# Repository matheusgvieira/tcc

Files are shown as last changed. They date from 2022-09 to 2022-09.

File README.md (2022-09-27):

# Desenvolvimento de protótipo funcional de hardware e firmware para monitoramento de instalações CC de sistemas fotovoltaicos

Este trabalho tem por objetivo o desenvolvimento de um hadware e firmware para o monitoramento, em tempo real, de caixas de junção de sistemas fotovoltaicos, viabilizando o acompanhamento de variáveis elétricas e estado de operação dos equipamentos.

### Estrututra

- Hardware: contém todos esquemáticos e layout de placa de circuito impressos, desenvolvidos no Altium.
- Firmware: contém o código fonte da placa de coleta de dados e da placa de comunicação, no CubeIde e ESP-IDF, respectivamente.
- Software: containers para criação do broker MQTT e o Dashboard no Node-red

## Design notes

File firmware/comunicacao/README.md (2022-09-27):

# Comunication Modulo

> The firmware from Tcc Project can perform the below features:
> Controller and send of data to MQTT Broker.

* Send data sensors to MQTT Broker

## Actuators

* Led

## Protocols

* UART
* MQTT

## Comandos ESP-IDF

1. Set enviroments of espressif idf
```sh
cd $HOME
. $HOME/esp/esp-idf/export.sh
```

3. Set develop board and settings configurations
```sh
idf.py set-target esp32
idf.py menuconfig
```

4. Build of project
```sh
idf.py build
```

5. Upload project in develop board
```sh
idf.py -p PORT [-b BAUD] flash
idf.py -p PORT flash monitor
```

6. See screen monitor
```sh
screen /dev/ttyUSB0 115200
```

## Dashboard
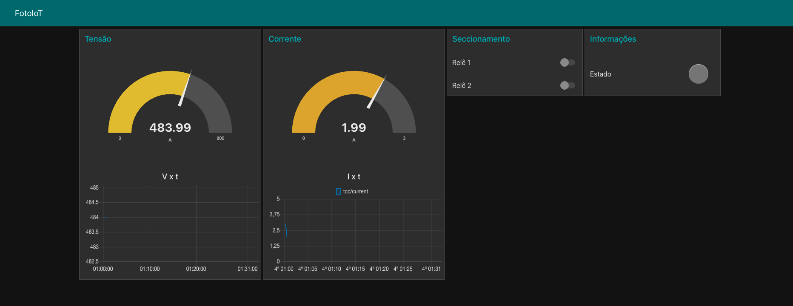
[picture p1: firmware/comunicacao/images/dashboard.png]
Dashboard


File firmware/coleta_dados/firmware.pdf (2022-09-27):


01/11/2021

## firmware Project Configuration Report

# 1. Description

## 1.1. Project

Project Name | firmware
Board Name | NUCLEO-G474RE
Generated with: | STM32CubeMX 6.3.0
Date | 11/01/2021

## 1.2. MCU

MCU Series | STM32G4
MCU Line | STM32G4x4
MCU name | STM32G474RETx
MCU Package | LQFP64
MCU Pin number | 64

## 1.3. Core(s) information

Core(s) | ARM Cortex-M4

# 2. Pinout Configuration

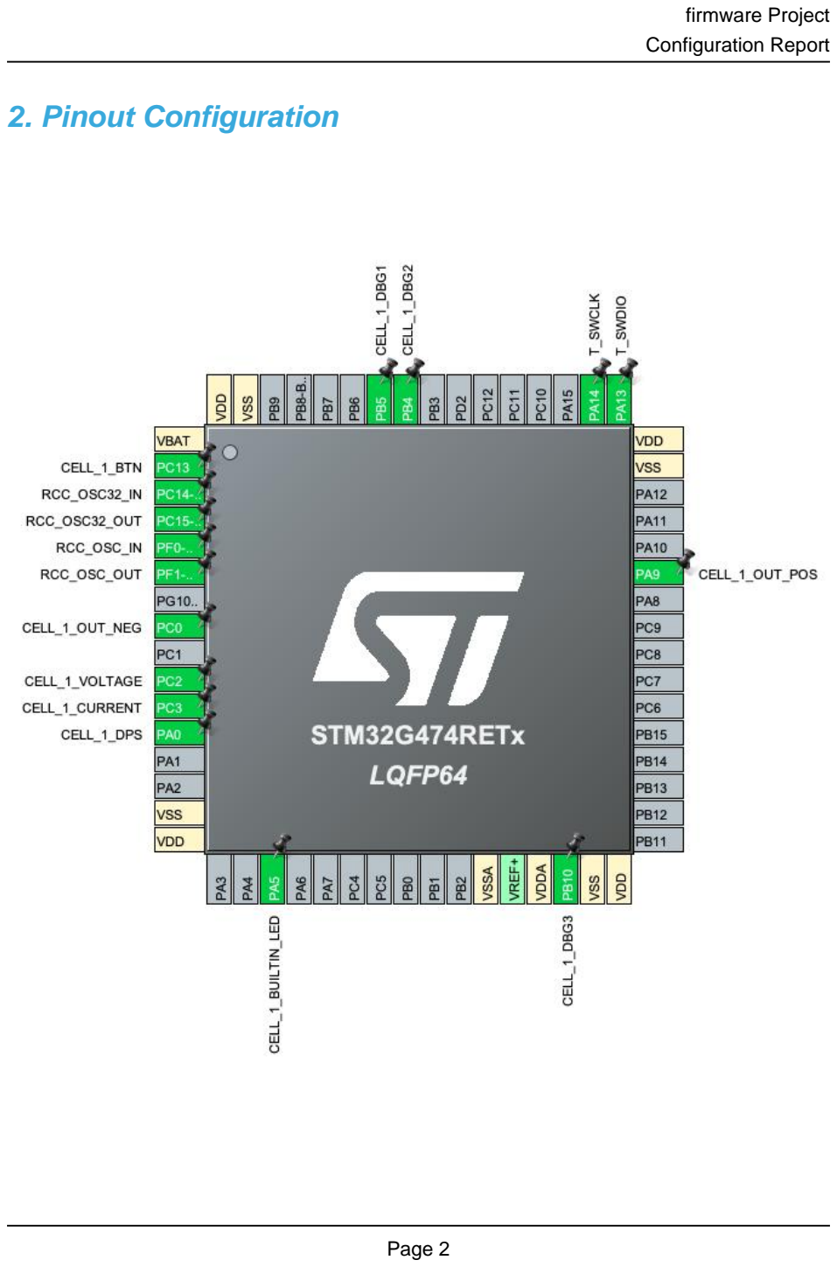
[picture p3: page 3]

# 3. Pins Configuration

Pin Number LQFP64 | Pin Name (function after reset) | Pin Type | Alternate Function(s) | Label
1 | VBAT | Power
2 | PC13 | I/O | GPIO_EXTI13 | CELL_1_BTN
3 | PC14-OSC32_IN | I/O | RCC_OSC32_IN
4 | PC15-OSC32_OUT | I/O | RCC_OSC32_OUT
5 | PF0-OSC_IN | I/O | RCC_OSC_IN
6 | PF1-OSC_OUT | I/O | RCC_OSC_OUT
8 | PC0 * | I/O | GPIO_Output | CELL_1_OUT_NEG
10 | PC2 | I/O | ADC1_IN8 | CELL_1_VOLTAGE
11 | PC3 | I/O | ADC2_IN9 | CELL_1_CURRENT
12 | PA0 | I/O | GPIO_EXTI0 | CELL_1_DPS
15 | VSS | Power
16 | VDD | Power
19 | PA5 * | I/O | GPIO_Output | CELL_1_BUILTIN_LED
27 | VSSA | Power
29 | VDDA | Power
30 | PB10 * | I/O | GPIO_Output | CELL_1_DBG3
31 | VSS | Power
32 | VDD | Power
43 | PA9 * | I/O | GPIO_Output | CELL_1_OUT_POS
47 | VSS | Power
48 | VDD | Power
49 | PA13 | I/O | SYS_JTMS-SWDIO | T_SWDIO
50 | PA14 | I/O | SYS_JTCK-SWCLK | T_SWCLK
57 | PB4 * | I/O | GPIO_Output | CELL_1_DBG2
58 | PB5 * | I/O | GPIO_Output | CELL_1_DBG1
63 | VSS | Power
64 | VDD | Power

## * The pin is affected with an I/O function

# 4. Clock Tree Configuration

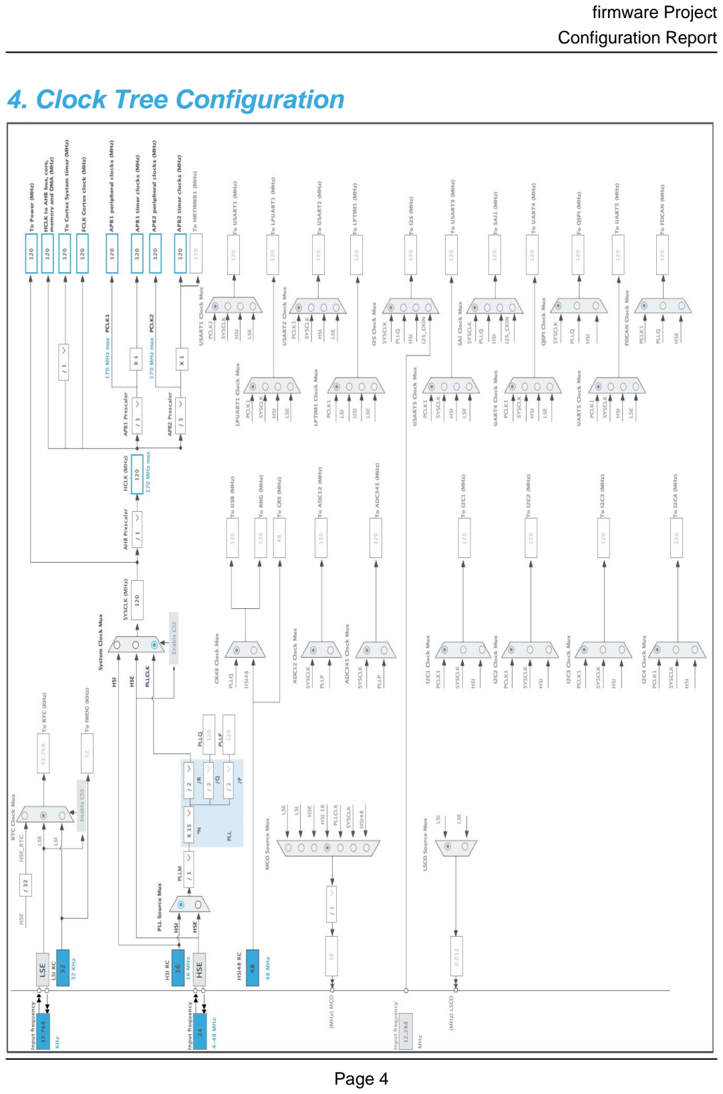
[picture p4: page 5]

# 5. Software Project

## 5.1. Project Settings

Name | Value
Project Name | firmware
Project Folder | /Users/rfeijoo/Documents/OneDrive/CubeMX/firmware
Toolchain / IDE | STM32CubeIDE
Firmware Package Name and Version | STM32Cube FW_G4 V1.4.0
Application Structure | Advanced
Generate Under Root | Yes
Do not generate the main() | No
Minimum Heap Size | 0x200
Minimum Stack Size | 0x400

## 5.2. Code Generation Settings

Name | Value
STM32Cube MCU packages and embedded software | Copy only the necessary library files
Generate peripheral initialization as a pair of '.c/.h' files | Yes
Backup previously generated files when re-generating | No
Keep User Code when re-generating | Yes
Delete previously generated files when not re-generated | Yes
Set all free pins as analog (to optimize the power consumption) | No
Enable Full Assert | No

## 5.3. Advanced Settings - Generated Function Calls

Rank | Function Name | Peripheral Instance Name
1 | MX_GPIO_Init | GPIO
2 | SystemClock_Config | RCC
3 | MX_TIM1_Init | TIM1
4 | MX_ADC1_Init | ADC1
5 | MX_ADC2_Init | ADC2
6 | MX_ADC5_Init | ADC5
7 | MX_TIM2_Init | TIM2

# 6. Power Consumption Calculator report

## 6.1. Microcontroller Selection

Series | STM32G4
Line | STM32G4x4
MCU | STM32G474RETx
Datasheet | DS12288_Rev0

## 6.2. Parameter Selection

Temperature | 25
Vdd | 3.0

## 6.3. Battery Selection

Battery | Li-SOCL2(A3400)
Capacity | 3400.0 mAh
Self Discharge | 0.08 %/month
Nominal Voltage | 3.6 V
Max Cont Current | 100.0 mA
Max Pulse Current | 200.0 mA
Cells in series | 1
Cells in parallel | 1

## 6.4. Sequence

Step | Step1 | Step2
Mode | RUN | STOP1
Vdd | 3.0 | 3.0
Voltage Source | Battery | Battery
Range | Range1-Boost | NoRange
Fetch Type | FLASH/DualBank/ART | NA
CPU Frequency | 170 MHz | 0 Hz
Clock Configuration | HSE BYP PLL | ALL CLOCKS OFF
Clock Source Frequency | 4 MHz | 0 Hz

### Peripherals

Additional Cons. | 0 mA | 0 mA
Average Current | 29.5 mA | 80.5 µA
Duration | 0.1 ms | 0.9 ms
DMIPS | 213.0 | 0.0
Ta Max | 124.25 | 129.98
Category | In DS Table | In DS Table

## 6.5. Results

Sequence Time | 1 ms | Average Current | 3.02 mA
Battery Life | 1 month, 16 days, 9 hours | Average DMIPS | 212.5 DMIPS

## 6.6. Chart

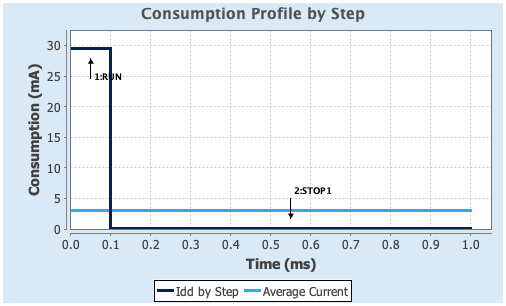
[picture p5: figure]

# 7. Peripherals and Middlewares Configuration

## 7.1. ADC1 IN8: IN8 Single-ended

## 7.1.1. Parameter Settings:

### ADCs_Common_Settings:

Mode | Dual regular simultaneous mode only *
DMA Access Mode | DMA access mode disabled
Delay between 2 sampling phases | 1 Cycle

### ADC_Settings:

Clock Prescaler | Synchronous clock mode divided by 2
Resolution | ADC 12-bit resolution
Data Alignment | Right alignment
Gain Compensation | 0
Scan Conversion Mode | Disabled
End Of Conversion Selection | End of sequence of conversion *
Low Power Auto Wait | Disabled
Continuous Conversion Mode | Disabled
Discontinuous Conversion Mode | Disabled
DMA Continuous Requests | Disabled
Overrun behaviour | Overrun data preserved

### ADC_Regular_ConversionMode:

Enable Regular Conversions | Enable
Enable Regular Oversampling | Disable
Number Of Conversion | 1
External Trigger Conversion Source | Regular Conversion launched by software
External Trigger Conversion Edge | None
Rank | 1
Channel | Channel 8
Sampling Time | 2.5 Cycles
Offset Number | No offset

### ADC_Injected_ConversionMode:

Enable Injected Conversions | Disable

### Analog Watchdog 1:

Enable Analog WatchDog1 Mode | false

### Analog Watchdog 2:

Enable Analog WatchDog2 Mode | false

### Analog Watchdog 3:

Enable Analog WatchDog3 Mode | false

## 7.2. ADC2 IN9: IN9 Single-ended

## 7.2.1. Parameter Settings:

### ADCs_Common_Settings:

Mode | Dual regular simultaneous mode only *
DMA Access Mode | DMA access mode disabled
Delay between 2 sampling phases | 1 Cycle

### ADC_Settings:

Clock Prescaler | Synchronous clock mode divided by 2
Resolution | ADC 12-bit resolution
Data Alignment | Right alignment
Gain Compensation | 0
Scan Conversion Mode | Disabled
End Of Conversion Selection | End of sequence of conversion *
Low Power Auto Wait | Disabled
Continuous Conversion Mode | Disabled
Discontinuous Conversion Mode | Disabled
DMA Continuous Requests | Disabled
Overrun behaviour | Overrun data preserved

### ADC_Regular_ConversionMode:

Enable Regular Conversions | Enable
Enable Regular Oversampling | Disable
Number Of Conversion | 1
Rank | 1
Channel | Channel 9
Sampling Time | 2.5 Cycles
Offset Number | No offset

### ADC_Injected_ConversionMode:

Enable Injected Conversions | Disable

### Analog Watchdog 1:

Enable Analog WatchDog1 Mode | false

### Analog Watchdog 2:

Enable Analog WatchDog2 Mode | false

### Analog Watchdog 3:

Enable Analog WatchDog3 Mode | false

## 7.3. ADC5 mode: Temperature Sensor Channel mode: Vrefint Channel

## 7.3.1. Parameter Settings:

### ADC_Settings:

Clock Prescaler | Synchronous clock mode divided by 2
Resolution | ADC 12-bit resolution
Data Alignment | Right alignment
Gain Compensation | 0
Scan Conversion Mode | Disabled
End Of Conversion Selection | End of single conversion
Low Power Auto Wait | Disabled
Continuous Conversion Mode | Disabled
Discontinuous Conversion Mode | Disabled
DMA Continuous Requests | Disabled
Overrun behaviour | Overrun data preserved

### ADC_Regular_ConversionMode:

Enable Regular Conversions | Enable
Enable Regular Oversampling | Disable
Number Of Conversion | 1
External Trigger Conversion Source | Regular Conversion launched by software
External Trigger Conversion Edge | None
Rank | 1
Channel | Channel Temperature Sensor
Sampling Time | 640.5 Cycles *
Offset Number | No offset

### ADC_Injected_ConversionMode:

Enable Injected Conversions | Disable

### Analog Watchdog 1:

Enable Analog WatchDog1 Mode | false

### Analog Watchdog 2:

Enable Analog WatchDog2 Mode | false

### Analog Watchdog 3:

Enable Analog WatchDog3 Mode | false

## 7.4. RCC

## High Speed Clock (HSE): Crystal/Ceramic Resonator Low Speed Clock (LSE) : Crystal/Ceramic Resonator

## 7.4.1. Parameter Settings:

### System Parameters:

VDD voltage (V) | 3.3
Instruction Cache | Enabled
Prefetch Buffer | Disabled
Data Cache | Enabled
Flash Latency(WS) | 3 WS (4 CPU cycle)

### RCC Parameters:

HSI Calibration Value | 64
HSE Startup Timout Value (ms) | 100
LSE Startup Timout Value (ms) | 5000

### Power Parameters:

Power Regulator Voltage Scale | Power Regulator Voltage Scale 1

### Peripherals Clock Configuration:

Generate the peripherals clock configuration | TRUE

## 7.5. SYS Debug: Serial Wire Timebase Source: SysTick mode: save power of non-active UCPD - deactive Dead Battery pull-up

## 7.6. TIM1 Clock Source : Internal Clock

## 7.6.1. Parameter Settings:

### Counter Settings:

Prescaler (PSC - 16 bits value) | 119 *
Counter Mode | Up
Dithering | Disable
Counter Period (AutoReload Register - 16 bits value ) | 1041 *
Internal Clock Division (CKD) | No Division
Repetition Counter (RCR - 16 bits value) | 0
auto-reload preload | Enable *

### Trigger Output (TRGO) Parameters:

Master/Slave Mode (MSM bit) | Disable (Trigger input effect not delayed)
Trigger Event Selection TRGO | Reset (UG bit from TIMx_EGR)
Trigger Event Selection TRGO2 | Reset (UG bit from TIMx_EGR)

## 7.7. TIM2 Clock Source : Internal Clock

## 7.7.1. Parameter Settings:

### Counter Settings:

Prescaler (PSC - 16 bits value) | 11999 *
Counter Mode | Up
Dithering | Disable
Counter Period (AutoReload Register - 32 bits value ) | 10000 *
Internal Clock Division (CKD) | No Division
auto-reload preload | Enable *

### Trigger Output (TRGO) Parameters:

Master/Slave Mode (MSM bit) | Disable (Trigger input effect not delayed)
Trigger Event Selection TRGO | Reset (UG bit from TIMx_EGR)

### * User modified value

# 8. System Configuration

## 8.1. GPIO configuration

IP | Pin | Signal | GPIO mode | GPIO pull/up pull down | Max Speed | User Label
ADC1 | PC2 | ADC1_IN8 | Analog mode | No pull-up and no pull-down | n/a | CELL_1_VOLTAGE
ADC2 | PC3 | ADC2_IN9 | Analog mode | No pull-up and no pull-down | n/a | CELL_1_CURRENT
RCC | PC14-OSC32_IN | RCC_OSC32_IN | n/a | n/a | n/a
| PC15-OSC32_OU T | RCC_OSC32_O UT | n/a | n/a | n/a
| PF0-OSC_IN | RCC_OSC_IN | n/a | n/a | n/a
| PF1-OSC_OUT | RCC_OSC_OUT | n/a | n/a | n/a
SYS | PA13 | SYS_JTMS-SWDIO | n/a | n/a | n/a | T_SWDIO
| PA14 | SYS_JTCK-SWCLK | n/a | n/a | n/a | T_SWCLK
GPIO | PC13 | GPIO_EXTI13 | External Interrupt Mode with Rising edge trigger detection | No pull-up and no pull-down | n/a | CELL_1_BTN
| PC0 | GPIO_Output | Output Push Pull | No pull-up and no pull-down | Low | CELL_1_OUT_NEG
| PA0 | GPIO_EXTI0 | External Interrupt Mode with Rising/Falling edge | No pull-up and no pull-down | n/a | CELL_1_DPS
| PA5 | GPIO_Output | Output Push Pull | No pull-up and no pull-down | Low | CELL_1_BUILTIN_LED
| PB10 | GPIO_Output | Output Push Pull | No pull-up and no pull-down | Low | CELL_1_DBG3
| PA9 | GPIO_Output | Output Push Pull | No pull-up and no pull-down | Low | CELL_1_OUT_POS
| PB4 | GPIO_Output | Output Push Pull | No pull-up and no pull-down | Low | CELL_1_DBG2
| PB5 | GPIO_Output | Output Push Pull | No pull-up and no pull-down | Low | CELL_1_DBG1

## 8.2. DMA configuration

## nothing configured in DMA service

## 8.3. NVIC configuration

## 8.3.1. NVIC

Interrupt Table | Enable | Preenmption Priority | SubPriority
Non maskable interrupt | true | 0 | 0
Hard fault interrupt | true | 0 | 0
Memory management fault | true | 0 | 0
Prefetch fault, memory access fault | true | 0 | 0
Undefined instruction or illegal state | true | 0 | 0
System service call via SWI instruction | true | 0 | 0
Debug monitor | true | 0 | 0
Pendable request for system service | true | 0 | 0
System tick timer | true | 0 | 0
EXTI line0 interrupt | true | 0 | 0
ADC1 and ADC2 global interrupt | true | 0 | 0
TIM1 update interrupt and TIM16 global interrupt | true | 0 | 0
TIM2 global interrupt | true | 0 | 0
EXTI line[15:10] interrupts | true | 0 | 0
ADC5 global interrupt | true | 0 | 0
PVD/PVM1/PVM2/PVM3/PVM4 interrupts through EXTI lines 16/38/39/40/41 | unused
Flash global interrupt | unused
RCC global interrupt | unused
TIM1 break interrupt and TIM15 global interrupt | unused
TIM1 trigger and commutation interrupts and TIM17 global interrupt | unused
TIM1 capture compare interrupt | unused
FPU global interrupt | unused

## 8.3.2. NVIC Code generation

Enabled interrupt Table | Select for init sequence ordering | Generate IRQ handler | Call HAL handler
Non maskable interrupt | false | true | false
Hard fault interrupt | false | true | false
Memory management fault | false | true | false
Prefetch fault, memory access fault | false | true | false
Undefined instruction or illegal state | false | true | false
System service call via SWI instruction | false | true | false
Debug monitor | false | true | false
Pendable request for system service | false | true | false
System tick timer | false | true | true

Enabled interrupt Table | Select for init sequence ordering | Generate IRQ handler | Call HAL handler
EXTI line0 interrupt | false | true | true
ADC1 and ADC2 global interrupt | false | true | true
TIM1 update interrupt and TIM16 global interrupt | false | true | true
TIM2 global interrupt | false | true | true
EXTI line[15:10] interrupts | false | true | true
ADC5 global interrupt | false | true | true

### * User modified value

# 9. System Views

## 9.1. Category view 9.1.1. Current

# 10. Docs & Resources

Type | Link
Datasheet | http://www.st.com/resource/en/datasheet/DM00431551.pdf
Reference manual | http://www.st.com/resource/en/reference_manual/DM00355726.pdf
Programming manual | http://www.st.com/resource/en/programming_manual/DM00046982.pdf
Errata sheet | http://www.st.com/resource/en/errata_sheet/DM00500968.pdf
Application note | http://www.st.com/resource/en/application_note/CD00160362.pdf
Application note | http://www.st.com/resource/en/application_note/CD00167594.pdf
Application note | http://www.st.com/resource/en/application_note/CD00259245.pdf
Application note | http://www.st.com/resource/en/application_note/CD00264342.pdf
Application note | http://www.st.com/resource/en/application_note/CD00264379.pdf
Application note | http://www.st.com/resource/en/application_note/DM00042534.pdf
Application note | http://www.st.com/resource/en/application_note/DM00072315.pdf
Application note | http://www.st.com/resource/en/application_note/DM00074240.pdf
Application note | http://www.st.com/resource/en/application_note/DM00081379.pdf
Application note | http://www.st.com/resource/en/application_note/DM00083249.pdf
Application note | http://www.st.com/resource/en/application_note/DM00121475.pdf
Application note | http://www.st.com/resource/en/application_note/DM00129215.pdf
Application note | http://www.st.com/resource/en/application_note/DM00151811.pdf
Application note | http://www.st.com/resource/en/application_note/DM00226326.pdf
Application note | http://www.st.com/resource/en/application_note/DM00257177.pdf
Application note | http://www.st.com/resource/en/application_note/DM00272912.pdf
Application note | http://www.st.com/resource/en/application_note/DM00311483.pdf
Application note | http://www.st.com/resource/en/application_note/DM00355687.pdf
Application note | http://www.st.com/resource/en/application_note/DM00380469.pdf
Application note | http://www.st.com/resource/en/application_note/DM00395696.pdf
Application note | http://www.st.com/resource/en/application_note/DM00442716.pdf

Application note | http://www.st.com/resource/en/application_note/DM00442720.pdf
Application note | http://www.st.com/resource/en/application_note/DM00493651.pdf
Application note | http://www.st.com/resource/en/application_note/DM00535045.pdf
Application note | http://www.st.com/resource/en/application_note/DM00536349.pdf
Application note | http://www.st.com/resource/en/application_note/DM00605707.pdf
Application note | http://www.st.com/resource/en/application_note/DM00607955.pdf
Application note | http://www.st.com/resource/en/application_note/DM00610467.pdf
Application note | http://www.st.com/resource/en/application_note/DM00625282.pdf
Application note | http://www.st.com/resource/en/application_note/DM00625700.pdf
Application note | http://www.st.com/resource/en/application_note/DM00725181.pdf

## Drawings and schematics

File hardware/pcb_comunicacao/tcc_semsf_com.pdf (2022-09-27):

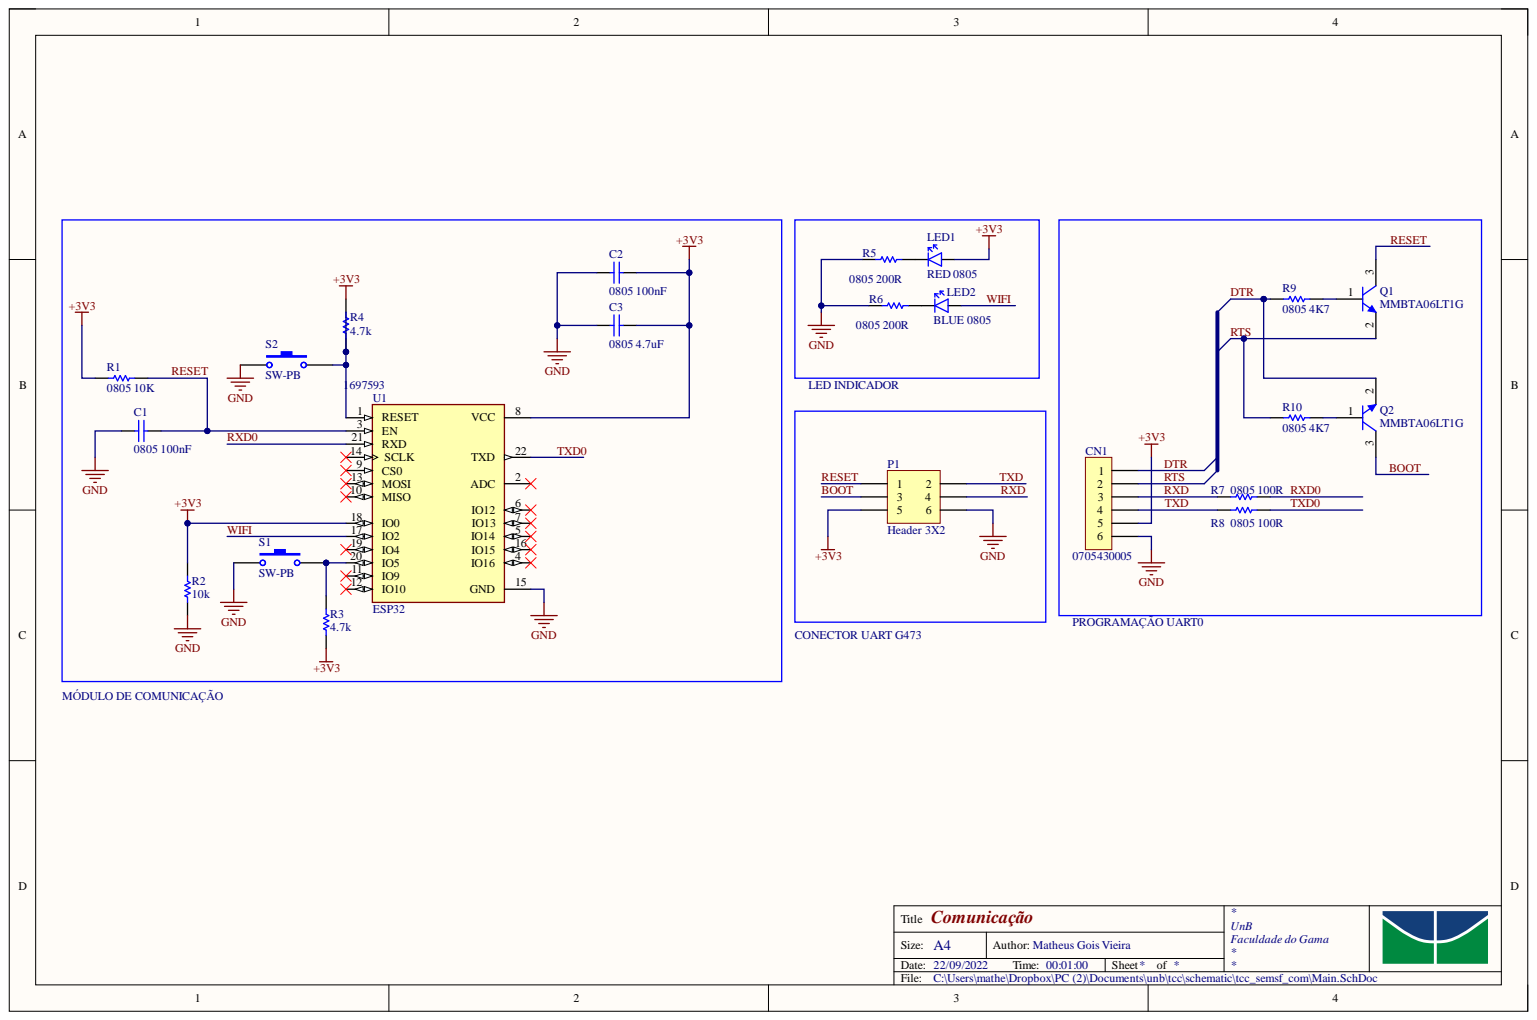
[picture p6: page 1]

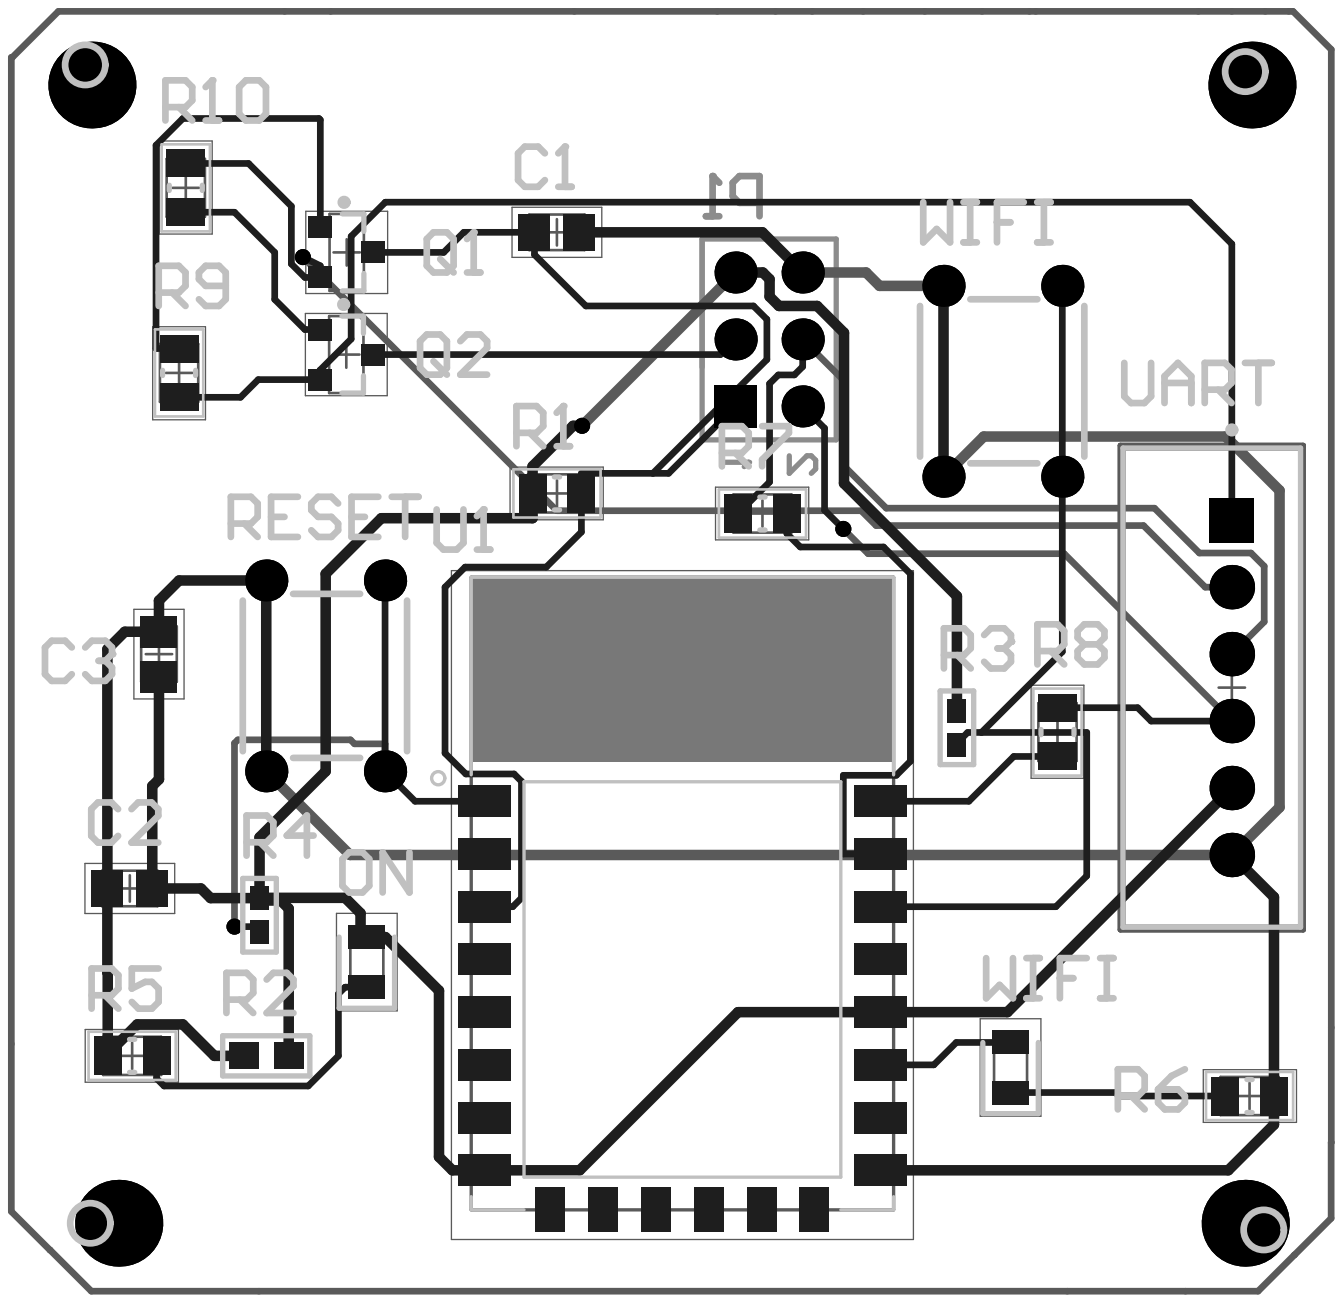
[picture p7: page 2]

BILL OF MATERIALS | Bill of Materials for Project [tcc_semsf_com.PrjPcb] (No PCB Document Selected)

### Organization:

### Author: Matheus Gois Vieira

### Project Name: tcc_semsf_com.PrjPcb

Revision: | Date:
# | Comment | Description | Manufacturer | Manufacturer Part Number | Case/Package | Supplier 1 | Supplier Part Number 1 | Designator | Quantity

1 | 0805 100nF | CC Series 0805 0.1 uF 50 V ±10 % Tolerance X7R SMT Multilayer Ceramic Capacitor | Yageo | CC0805KRX7R9BB104 | 805 | Digi-Key | 311-1140-2-ND | C1, C2 | 2
2 | 0805 4.7uF | 4.7uF ±10% 50V 0805 | TDK | C2012X5R1H475K125AB | 805 | RSComponents | 7883041 | C3 | 1
3 | 705430005 | Conn Shrouded Header (4 Sides) HDR 6 POS 2.54mm Solder ST Top Entry Thru-Hole SL™ Tube | Molex | 705430005 | | RSComponents | 6792483 | CN1 | 1
4 | RED 0805 | Red SMD 625nm LED Indication - Discrete 2V 0805 (2012 Metric) | | | | | | LED1 | 1
5 | BLUE 0805 | Red SMD 625nm LED Indication - Discrete 2V 0805 (2012 Metric) | | | | | | LED2 | 1
6 | Header 3X2 | Header, 3-Pin, Dual row | | | | | | P1 | 1
7 | MMBTA06LT1G | Trans GP BJT NPN 80V 0.5A 3-Pin SOT-23 T/R | ON Semiconductor | MMBTA06LT1G | SOT-23-3 | Digi-Key | MMBTA06LT1GOSCT-ND | Q1, Q2 | 2
8 | 0805 10K | 10K Omhs 0805 ± 1.00% 0.125W ± 100ppm/℃ | Yageo | RC0603FR-0710KL | 603 | RSComponents | 6185163 | R1 | 1
9 | 10k | Res, 10K, 0.01%, 0.25W, 1206, Metal Foil | | Y163010K0000T9R | 1206 | Digi-Key | Y1630-10.0KBCT-ND | R2 | 1
10 | 4.7k | Res Thick Film 1206 4.7K Ohm 5% 1/4W ±200ppm/°C Molded SMD Punched Carrier T/R | | ERJ-8GEYJ472V | 1206 | New ark | 65T8944 | R3, R4 | 2
11 | 0805 200R | 200 Ohm 0805 ± 1.00% 0.125W ± 100ppm/℃ | Yageo | RC0603FR-07200RL | 603 | RSComponents | 6183842 | R5, R6 | 2
12 | 0805 100R | 100R ± 1.00% 0.125W ± 100ppm/℃ 0805 | Yageo | RC0805FR-07100RL | 805 | RSComponents | 6185135 | R7, R8 | 2
13 | 0805 4K7 | 4700Ω ± 1.00% 0.125W ± 100ppm/℃ 0805 | Yageo | RC0805FR-074K7L | 805 | RSComponents | 6181408 | R9, R10 | 2
14 | SW-PB | Tactile Sw itch | | | | | | S1, S2 | 2
15 | ESP32 | This WiFi module has a 32-bit MCU micro and clock speeds supporting 80 MHz or 160 MHz. Supports the RTOS and integrated Wi-Fi MAC/BB/RF/PA/LNA, and has an on-board antenna. | | | | RSComponents | 1697593 | U1 | 1
Approved | | | Notes | | | | | | 22

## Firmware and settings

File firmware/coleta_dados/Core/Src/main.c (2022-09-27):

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
/* Includes ------------------------------------------------------------------*/
#include "main.h"
#include "adc.h"
#include "tim.h"
#include "gpio.h"

/* USER CODE BEGIN Includes */
#include <stdio.h>
#include "meas.h"
#include "objects_def.h"
#include "events.h"
/* USER CODE END Includes */


void SystemClock_Config(void);
/* USER CODE BEGIN 0 */
int _write(int file, char *ptr, int len)
{
	for (int i=0 ; i<len ; i++)
		ITM_SendChar((*ptr++));

	return (len);
}
/* USER CODE END 0 */

/**
  * @brief  The application entry point.
  * @retval int
  */
int main(void)
{
  /* MCU Configuration--------------------------------------------------------*/

  /* Reset of all peripherals, Initializes the Flash interface and the Systick. */
  HAL_Init();

  /* Configure the system clock */
  SystemClock_Config();

  /* Initialize all configured peripherals */
  MX_GPIO_Init();
  MX_TIM1_Init();
  MX_ADC1_Init();
  MX_ADC2_Init();
  MX_ADC5_Init();
  MX_TIM2_Init();
  /* USER CODE BEGIN 2 */
  printf("-- Starting System's Configuration\n\n");

  objects_def_init();

  HAL_ADCEx_Calibration_Start(&hadc5, ADC_SINGLE_ENDED);

  HAL_TIM_Base_Start_IT(&htim1);
  HAL_TIM_Base_Start_IT(&htim2);

  printf("-- End of System's Configuration\n");
  /* USER CODE END 2 */

  /* Infinite loop */
  /* USER CODE BEGIN WHILE */
  while (1)
  {
	objects_def_loop();
    /* USER CODE END WHILE */

    /* USER CODE BEGIN 3 */
  }
  /* USER CODE END 3 */
}

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


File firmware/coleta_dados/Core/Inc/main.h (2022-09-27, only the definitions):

#define CELL_1_BTN_Pin GPIO_PIN_13
#define CELL_1_BTN_GPIO_Port GPIOC
#define CELL_1_BTN_EXTI_IRQn EXTI15_10_IRQn
#define CELL_1_OUT_NEG_Pin GPIO_PIN_0
#define CELL_1_OUT_NEG_GPIO_Port GPIOC
#define CELL_1_VOLTAGE_Pin GPIO_PIN_2
#define CELL_1_VOLTAGE_GPIO_Port GPIOC
#define CELL_1_CURRENT_Pin GPIO_PIN_3
#define CELL_1_CURRENT_GPIO_Port GPIOC
#define CELL_1_DPS_Pin GPIO_PIN_0
#define CELL_1_DPS_GPIO_Port GPIOA
#define CELL_1_DPS_EXTI_IRQn EXTI0_IRQn
#define CELL_1_BUILTIN_LED_Pin GPIO_PIN_5
#define CELL_1_BUILTIN_LED_GPIO_Port GPIOA
#define CELL_1_DBG3_Pin GPIO_PIN_10
#define CELL_1_DBG3_GPIO_Port GPIOB
#define CELL_1_OUT_POS_Pin GPIO_PIN_9
#define CELL_1_OUT_POS_GPIO_Port GPIOA
#define T_SWDIO_Pin GPIO_PIN_13
#define T_SWDIO_GPIO_Port GPIOA
#define T_SWCLK_Pin GPIO_PIN_14
#define T_SWCLK_GPIO_Port GPIOA
#define CELL_1_DBG2_Pin GPIO_PIN_4
#define CELL_1_DBG2_GPIO_Port GPIOB
#define CELL_1_DBG1_Pin GPIO_PIN_5
#define CELL_1_DBG1_GPIO_Port GPIOB
#define VCC					3.3
#define ADC_RES_BITS		4095.0
#define WORD_LENGTH			32
#define HALF_WORD_LENGTH	16
#define LSB_WORD_BIT_MASK	0xFFFF

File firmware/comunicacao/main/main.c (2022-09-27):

#include "generic_digital_output.h"
#include "freertos/task.h"
#include "structures.h"
#include "esp_log.h"
#include "button.h"
#include "mqtt.h"
#include "uart.h"
#include "wifi.h"

const char* TAG = "STRBIOT";

TaskHandle_t mqtt_task_handle;

com_module module = { .read_uart = "",
                      .voltage = 0.0,
                      .current = 0.0,
                      .power = 0.0,
                      .energy = 0.0,
                      .topic_current = "tcc/current",
                      .topic_voltage = "tcc/voltage",
                      .topic_power = "tcc/power",
                      .topic_energy = "tcc/energy",
                      .topic_debug = "/debug",
                      .update = 0,
                      .relay1 = 0,
                      .relay2 = 0};

digital_output led_main = {.pin = 25, .tag= "white"};

mqtt_message_t mqtt_message_state_module = {.topic = "tcc/state", .payload = 1.0, .tag = "current_state"};

mqtt_message_t mqtt_message_relay1 = {.topic = "tcc/relay_1", .pin_relay = 33};

mqtt_message_t mqtt_message_relay2 = {.topic = "tcc/relay_2", .pin_relay = 32};

static const int module_queue_len = 5;

QueueHandle_t module_queue;

SemaphoreHandle_t xSemaphore = NULL;

wifi_credentials credentials = {.ssid = "", .password = ""};

void app_main()
{
    initialize_digital_output(&led_main);

    set_state_digital_output(&led_main, 1);

    get_init_nvs(&module);

    initialization_uart();

    module_queue = xQueueCreate(module_queue_len, sizeof (com_module));

    get_wifi_credentials(&credentials);

    ESP_LOGI(TAG, "ssid = %s\n", credentials.ssid);
    ESP_LOGI(TAG, "password = %s\n", credentials.password);

    if (check_credentials(&credentials)) {
        setup_wifi();
    } else {
        if (wifi_connect_sta(&credentials)) {

            xTaskCreate(mqtt_publish_state_task,
                        "publish_current_state",
                        1024*4,
                        &mqtt_message_state_module,
                        2,
                        &mqtt_task_handle
            );

            xTaskCreate(mqtt_subscriber_relay_1_task,
                        "subscriber_rele1_state",
                        1024*4,
                        &mqtt_message_relay1,
                        2,
                        NULL
            );

            xTaskCreate(mqtt_subscriber_relay_2_task,
                        "subscriber_rele2_state",
                        1024*4,
                        &mqtt_message_relay2,
                        2,
                        NULL
            );


            xTaskCreate(receive_message_uart,
                        "read_byte_uart",
                        1024*4,
                        &module,
                        2,
                        NULL
            );

            xTaskCreate(mqtt_publish_data_task,
                        "publish_values_got",
                        1024*4,
                        &module,
                        2,
                        &mqtt_task_handle
            );

            xTaskCreate(reset_credentials_wifi_button,
                        "reset_credentials_wifi_button",
                        1024*4,
                        NULL,
                        2,
                        NULL
            );

        }
    }
}

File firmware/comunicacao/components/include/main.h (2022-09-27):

//
// Created by Matheus Gois Vieira on 24/09/22.
//

#ifndef COM_MODULE_MAIN_H
#define COM_MODULE_MAIN_H

#include <stdio.h>
#include <string.h>
#include "esp_log.h"
#include "driver/uart.h"
#include "driver/gpio.h"
#include "sdkconfig.h"

#define BUTTON_RESET_WIFI   GPIO_NUM_32
#define LED_ON_OFF          GPIO_NUM_25
#define LED_WIFI            GPIO_NUM_26
#define UART_TXD_PIN        GPIO_NUM_17
#define UART_RXD_PIN        GPIO_NUM_16

#endif //COM_MODULE_MAIN_H

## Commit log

2022-03-07 feat(power_supply): first commit of project, added power supply
    [cond_sinais.SchDoc, power_supply.SchDoc, tcc_semsf.PrjPcb]
2022-03-14 Finished components especification
    [cond_sinais.SchDoc]
2022-03-14 Finished sinal conditional current and voltage
    [cond_sinais.SchDoc]
2022-03-14 :hammer: annotation components
    [cond_sinais.SchDoc]
2022-03-18 Build seccionamento, and begin controlador and comunicador
    [comunicacao.SchDoc, cond_sinais.SchDoc, controlador.SchDoc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]
2022-04-02 Finished comunicacao and begin conection controlador
    [comunicacao.SchDoc, controlador.SchDoc]
2022-04-04 Finished controlador.
    [comunicacao.SchDoc, cond_sinais.SchDoc, controlador.SchDoc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]
2022-04-04 Ajuste no bug conector 3v3
    [comunicacao.SchDoc, cond_sinais.SchDoc, controlador.SchDoc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]
2022-04-30 Refactor and add dps
    [cond_sinais.SchDoc, controlador.SchDoc, perifericos.SchDoc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]
2022-05-01 Add mainc schematic
    [Main.SchDoc, comunicacao.SchDoc, cond_sinais.SchDoc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]
2022-05-01 Compile project
    [cond_sinais.SchDoc, perifericos.SchDoc, power_supply.SchDoc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]
2022-09-19 PCB Finished
    [tcc_semsf.PrjPcb]
2022-09-27 Update repo tcc
    [Main.PcbDoc, Main.SchDoc, comunicacao.SchDoc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]

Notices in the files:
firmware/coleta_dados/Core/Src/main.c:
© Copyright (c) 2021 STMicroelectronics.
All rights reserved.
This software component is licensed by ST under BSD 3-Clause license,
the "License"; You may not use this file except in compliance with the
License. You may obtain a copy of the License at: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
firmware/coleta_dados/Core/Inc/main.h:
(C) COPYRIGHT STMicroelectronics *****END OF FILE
